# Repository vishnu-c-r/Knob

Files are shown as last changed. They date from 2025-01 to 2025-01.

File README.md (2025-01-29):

# SmartKnob Project

A **haptic feedback rotary knob** that uses a BLDC motor, a magnetic encoder, and a microcontroller to simulate dynamic resistance, detents, and end-stops. This repository contains the hardware schematics, firmware, and any software tooling needed to build a SmartKnob capable of providing programmable tactile feedback.

## Features

- **Brushless DC Motor (BLDC) Actuation**  
  Provides smooth, programmable torque for simulating detents, stops, and variable friction.
- **Magnetic Encoder**  
  High-resolution angle sensing ensures precise readings of knob position for responsive haptic effects.
- **Microcontroller-Based Control**  
  Real-time control loop to modulate motor torque based on the current knob position and configured haptic profile.
- **Configurable Haptic Profiles**  
  Switch between profiles like soft detents, hard stops, free spin, and others at runtime.
- **Integrated IMU (Optional)**  
  Measures orientation or additional movement data if advanced features are needed (e.g., inertia simulation).

## Hardware Overview

1. **Microcontroller**  
   - **ESP32-S3** (or your chosen MCU) running the main control loop, reading encoder data, and driving the motor driver via PWM signals.

2. **Motor Driver**  
   - **TMC6300** (or equivalent) controlling the 3-phase BLDC gimbal motor. Capable of precise torque modulation at low voltages.

3. **Magnetic Encoder**  
   - **AS5600** or similar to read the knob position.  
   - Offers contactless angle measurement with 12–14 bits of resolution.

4. **Motor**  
   - A gimbal-style BLDC motor (e.g., GB2208) for low cogging torque and smooth rotation.

5. **Power Supply**  
   - A 5V supply or battery pack, regulated down to 3.3V for the microcontroller.  
   - Make sure your motor driver supply is sized for peak current demands.

6. **Optional IMU**  
   - An MPU6050 or another IMU for advanced inertial-based haptic effects.

<!-- ## Firmware Structure

- **Encoder Reading**  
  Reads magnetic encoder via I2C/SPI to get current angle.  
- **Torque Control**  
  Uses PWM signals to drive the BLDC motor. Basic approach might be trapezoidal commutation or a custom approach; advanced setups can use FOC (Field-Oriented Control).  
- **Haptic Profiles**  
  Different modes (e.g., detents, end-stops, friction) defined in code. The firmware calculates desired torque based on the current angle and active profile.  
- **Main Loop**  
  Runs at a suitable update rate (e.g., 1–2 kHz) to read the angle, compute desired motor torque, and send PWM outputs to the motor driver.

<!-- ## Getting Started -->

<!-- 1. **Clone this repository**  
   ```bash
   git clone https://github.com/<your-username>/SmartKnob.git
   cd SmartKnob
   ```

2. **Hardware Assembly**  
   - Solder or assemble the PCB, including the motor driver, microcontroller, encoder, and any connectors.  
   - Mount the BLDC motor and magnet for the encoder so they align properly.

3. **Firmware Deployment**  
   - Open the firmware folder in your preferred IDE (e.g., PlatformIO, Arduino IDE).  
   - Adjust pin mappings in `config.h` for your specific wiring.  
   - Upload the firmware to your MCU.

4. **Configuration**  
   - In `config.h`, set motor parameters, encoder offsets, or other constants.  
   - If using an IMU, enable and configure it in `imu.h`.

5. **Testing**  
   - Power on the system and turn the knob.  
   - Observe motor feedback. If configured with a detent profile, you should feel discrete steps. --> 

## Usage

- **Change Haptic Mode**  
  By default, the firmware might start in free-spin. Use serial commands or a button (if implemented) to cycle through modes like detent, friction, or fixed end-stops.

- **Calibrate Encoder**  
  Ensure the knob is at a known reference angle if your system requires zero-position alignment. Some code might handle offset automatically.

- **Safety Notes**  
  - The motor driver can produce torque. Be cautious of pinch points.  
  - Avoid over-current situations by setting current limits if your driver supports it.

## Contributing

1. **Fork the repository** and create your branch from `main`.  
2. **Commit your changes** and push to your fork.  
3. **Open a Pull Request** detailing your modifications or improvements.

## License

This project is licensed under the [MIT License](LICENSE.md) — you are free to modify and distribute with attribution. See the LICENSE file for details.

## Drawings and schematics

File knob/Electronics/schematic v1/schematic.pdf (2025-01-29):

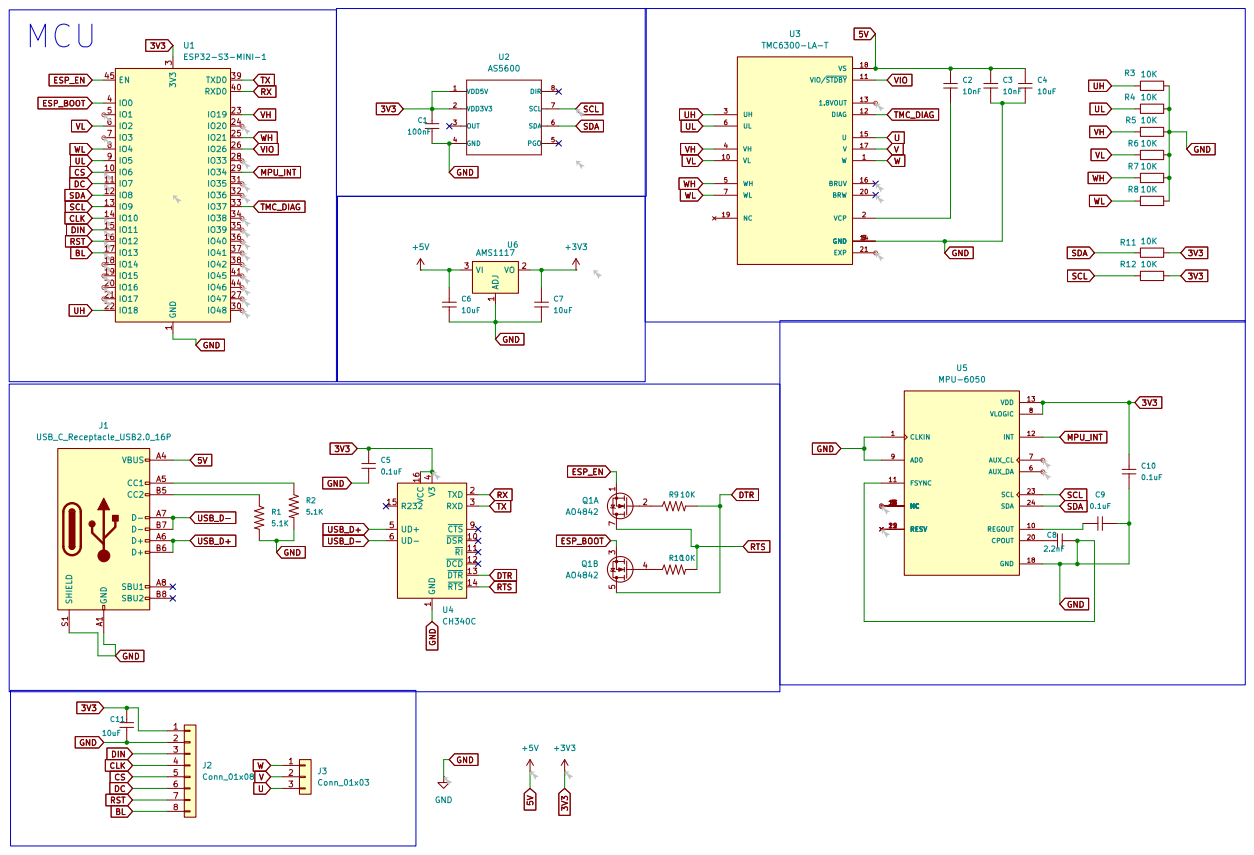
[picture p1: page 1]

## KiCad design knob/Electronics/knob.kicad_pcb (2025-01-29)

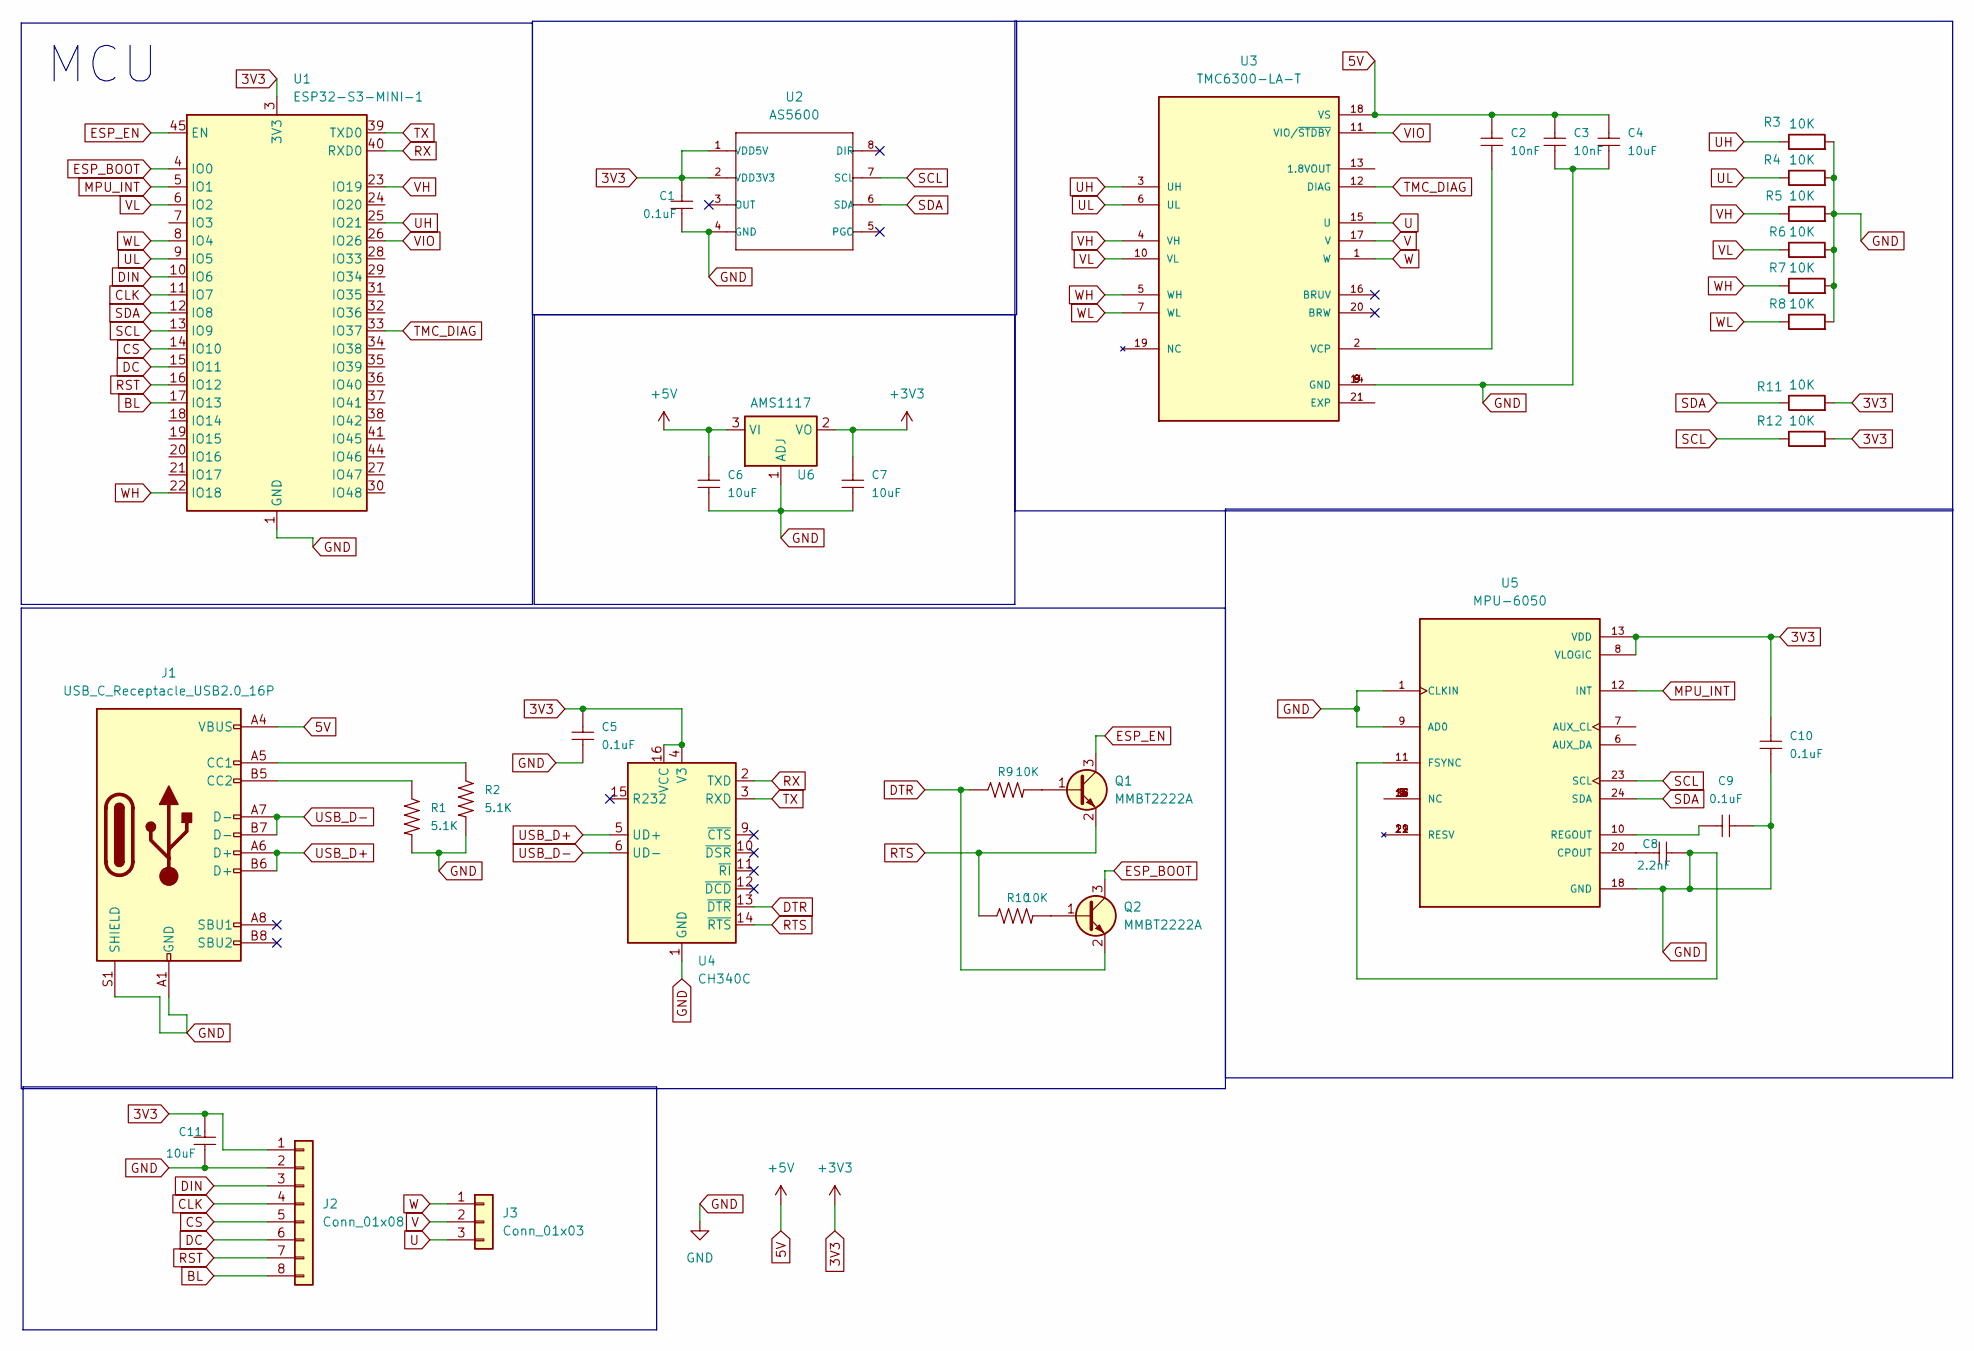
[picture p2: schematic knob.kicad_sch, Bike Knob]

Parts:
C1, C5, C9, C10: 0.1uF; C_0805_2012Metric
C2, C3: 10nF; C_0805_2012Metric
C4, C6, C7, C11: 10uF; C_0805_2012Metric
C8: 2.2nF; C_0805_2012Metric
J1: USB_C_Receptacle_USB2.0_16P; USB_C_Receptacle_GCT_USB4110
J2: Conn_01x08; PinSocket_1x08_P1.00mm_Vertical_SMD_Pin1Left
J3: Conn_01x03; JST_EH_S3B-EH_1x03_P2.50mm_Horizontal
Q1, Q2: MMBT2222A; SOT-23
R1, R2: 5.1K; R_0805_2012Metric_Pad1.20x1.40mm_HandSolder
R3, R4, R5, R6, R7, R8, R9, R10, R11, R12: 10K; R_0805_2012Metric_Pad1.20x1.40mm_HandSolder
U1: ESP32-S3-MINI-1; ESP32-S2-MINI-1
U2: AS5600
U3: TMC6300-LA-T; QFN40P300X300X90-21N; PARTREV 1.08
U4: CH340C; SOIC-16_3.9x9.9mm_P1.27mm
U5: MPU-6050; QFN50P400X400X95-24N; PARTREV 3.4
U6: AMS1117; SOT-223-3_TabPin2

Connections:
3V3: C1.2, C5.2, C7.2, C10.2, C11.2, J2.1, R11.2, R12.2, U1.3 (3V3), U2.1 (VDD5V), U2.2 (VDD3V3), U4.4 (V3), U4.16 (VCC), U5.8 (VLOGIC), U5.13 (VDD), U6.2 (VO)
5V: C2.2, C3.2, C4.2, C6.2, J1.A4 (VBUS), J1.A9 (VBUS), J1.B4 (VBUS), J1.B9 (VBUS), U3.18 (VS), U6.3 (VI)
BL: J2.8, U1.17 (IO13)
CLK: J2.4, U1.11 (IO7)
CS: J2.5, U1.14 (IO10)
DC: J2.6, U1.15 (IO11)
DIN: J2.3, U1.10 (IO6)
DTR: Q2.2 (E), R9.1, U4.13 (~DTR)
ESP_BOOT: Q2.3 (C), U1.4 (IO0)
ESP_EN: Q1.3 (C), U1.45 (EN)
GND: C1.1, C3.1, C4.1, C5.1, C6.1, C7.1, C8.1, C9.1, C10.1, C11.1, J1.A1 (GND), J1.A12 (GND), J1.B1 (GND), J1.B12 (GND), J1.S1 (SHIELD), J2.2, R1.2, R2.2, R3.2, R4.2, R5.2, R6.2, R7.2, R8.2, U1.1 (GND), U1.2 (GND), U1.42 (GND), U1.43 (GND), U1.46 (GND), U1.47 (GND), U1.48 (GND), U1.49 (GND), U1.50 (GND), U1.51 (GND), U1.52 (GND), U1.53 (GND), U1.54 (GND), U1.55 (GND), U1.56 (GND), U1.57 (GND), U1.58 (GND), U1.59 (GND), U1.60 (GND), U1.61 (GND), U1.62 (GND), U1.63 (GND), U1.64 (GND), U1.65 (GND), U2.4 (GND), U3.8 (VS), U3.9 (GND), U3.14 (GND), U4.1 (GND), U5.1 (CLKIN), U5.9 (AD0), U5.11 (FSYNC), U5.18 (GND), U6.1 (ADJ)
MPU_INT: U1.5 (IO1), U5.12 (INT)
unnamed: J1.A5 (CC1), R2.1
unnamed: J1.B5 (CC2), R1.1
unnamed: Q1.1 (B), R9.2
unnamed: Q2.1 (B), R10.2
unnamed: C2.1, U3.2 (VCP)
unnamed: C8.2, U5.20 (CPOUT)
unnamed: U5.2 (NC), U5.3 (NC), U5.4 (NC), U5.5 (NC), U5.14 (NC), U5.15 (NC), U5.16 (NC), U5.17 (NC)
unnamed: C9.2, U5.10 (REGOUT)
RST: J2.7, U1.16 (IO12)
RTS: Q1.2 (E), R10.1, U4.14 (~RTS)
RX: U1.40 (RXD0), U4.2 (TXD)
SCL: R12.1, U1.13 (IO9), U2.7 (SCL), U5.23 (SCL)
SDA: R11.1, U1.12 (IO8), U2.6 (SDA), U5.24 (SDA)
TMC_DIAG: U1.33 (IO37), U3.12 (DIAG)
TX: U1.39 (TXD0), U4.3 (RXD)
U: J3.3, U3.15 (U)
UH: R3.1, U1.25 (IO21), U3.3 (UH)
UL: R4.1, U1.9 (IO5), U3.6 (UL)
USB_D+: J1.A6 (D+), J1.B6 (D+), U4.5 (UD+)
USB_D-: J1.A7 (D-), J1.B7 (D-), U4.6 (UD-)
V: J3.2, U3.17 (V)
VH: R5.1, U1.23 (IO19), U3.4 (VH)
VIO: U1.26 (IO26), U3.11 (VIO/~STDBY)
VL: R6.1, U1.6 (IO2), U3.10 (VL)
W: J3.1, U3.1 (W)
WH: R7.1, U1.22 (IO18), U3.5 (WH)
WL: R8.1, U1.8 (IO4), U3.7 (WL)

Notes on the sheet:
MCU

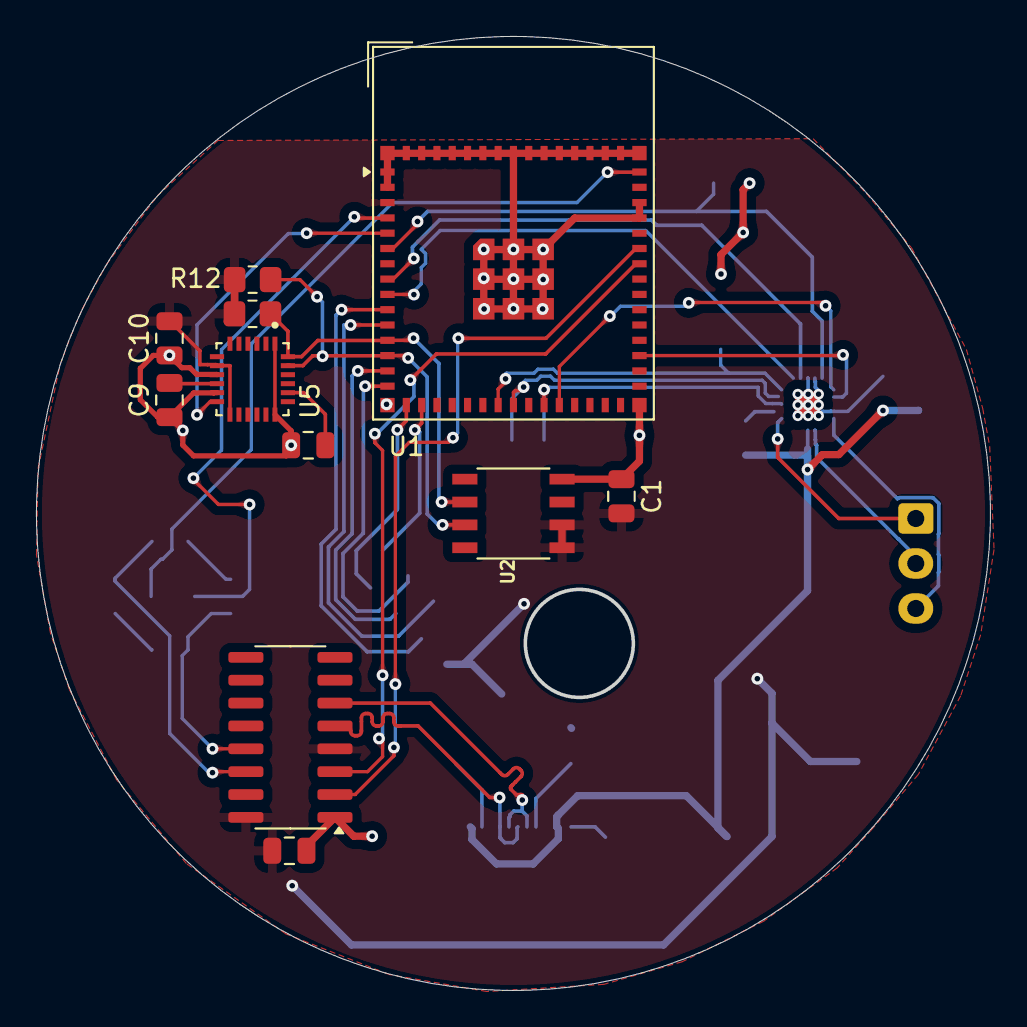
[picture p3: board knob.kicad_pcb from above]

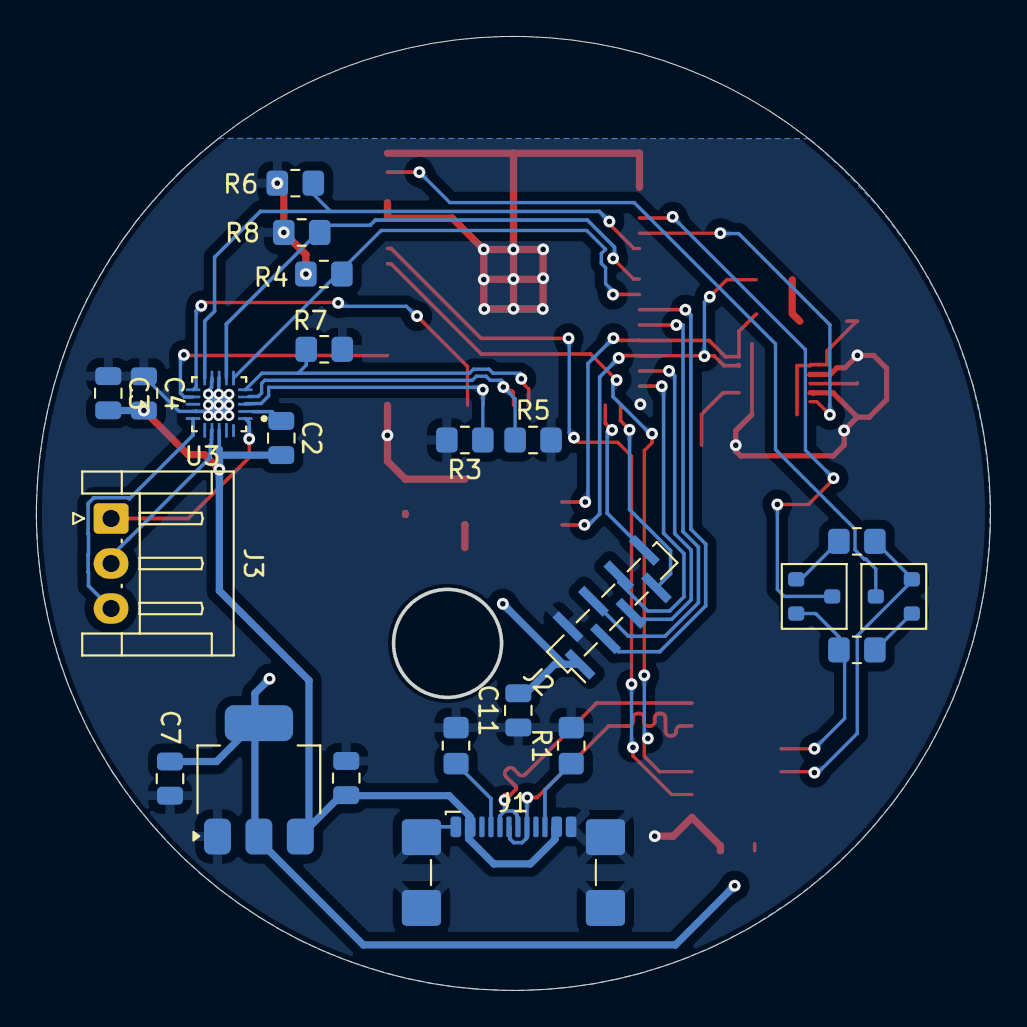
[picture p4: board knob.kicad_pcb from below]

Board: 2 copper layers, 53.0 x 53.0 mm, 34 parts (23 on the bottom side), 39 nets.

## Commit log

2025-01-29 initial prototype
    [knob-B_Cu.gbr, knob-B_Mask.gbr, knob-B_Paste.gbr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]
2025-01-31 reordered files
    [knob-B_Cu.gbr, knob-B_Mask.gbr, knob-B_Paste.gbr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]
